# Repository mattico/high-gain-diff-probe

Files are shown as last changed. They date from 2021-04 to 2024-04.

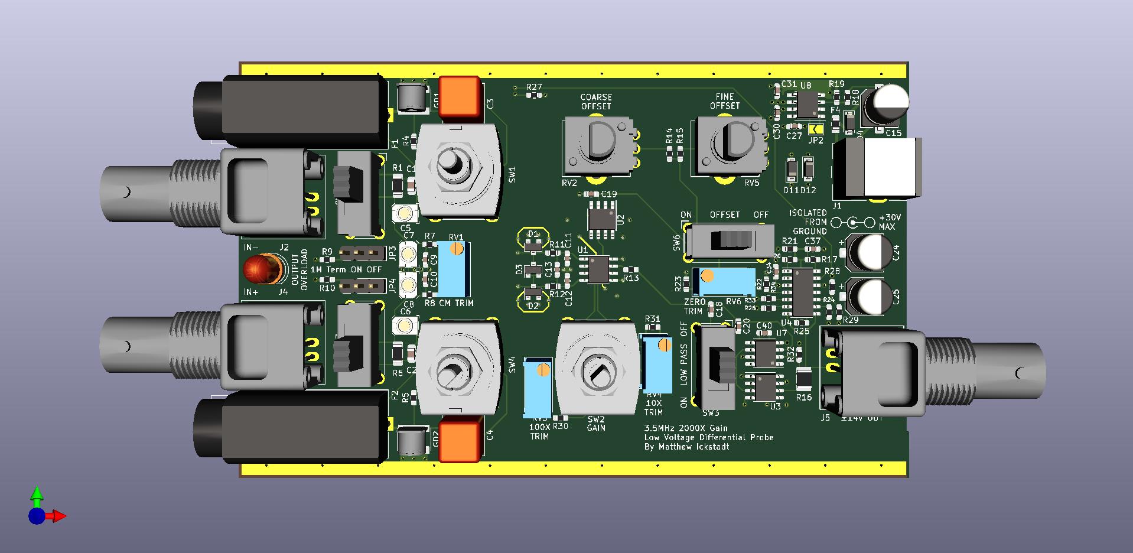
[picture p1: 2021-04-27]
Images/TopRender.jpg

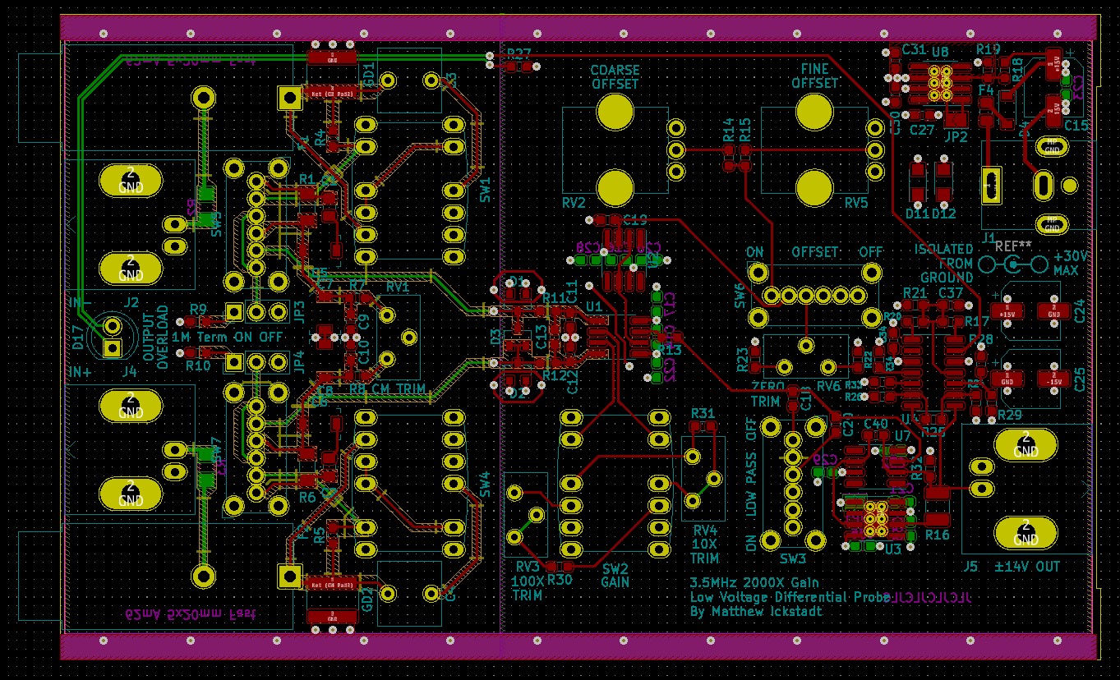
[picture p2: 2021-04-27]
Images/PCBTraces.jpg

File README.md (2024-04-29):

# High Gain Differential Probe

This was my attempt at a high gain (2000X) low-noise differential probe, for use in electronics testing.

Be warned that I haven't gotten this working. IIRC the issue was that it would oscillate or saturate. I didn't look into it too thoroughly, it's possible that there is an easy fix.

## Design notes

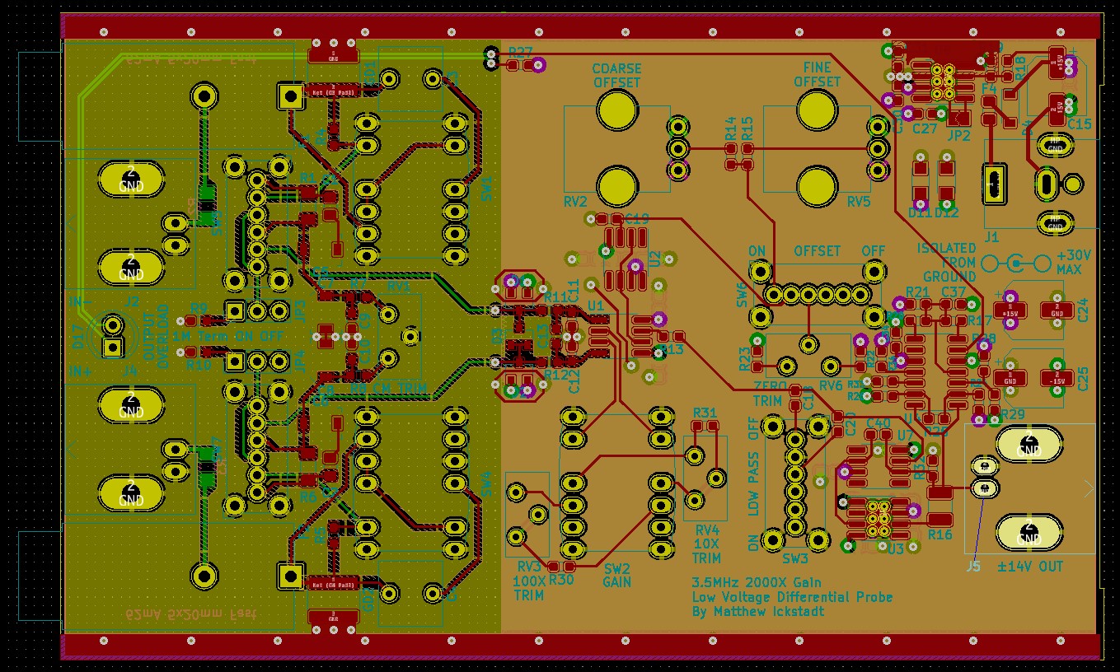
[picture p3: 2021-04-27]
Images/PCBFilled.jpg

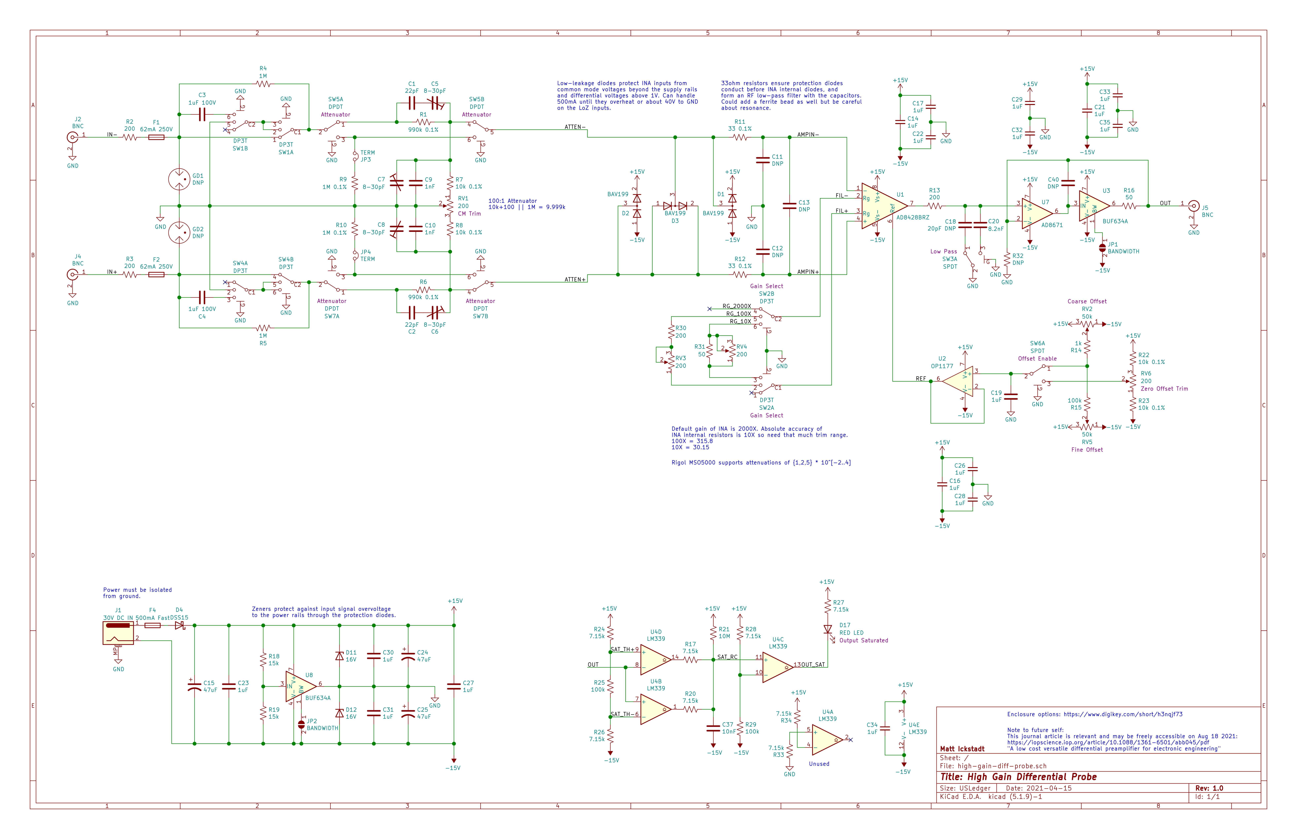
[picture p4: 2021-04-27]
Images/high-gain-diff-probe.png

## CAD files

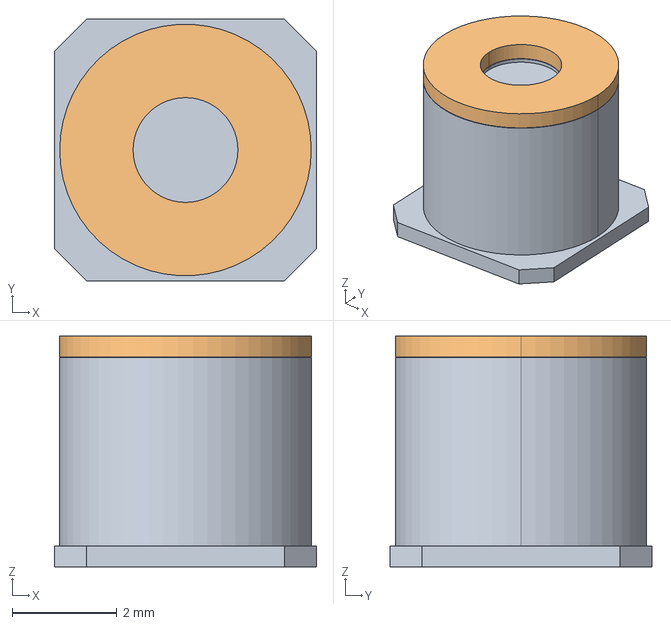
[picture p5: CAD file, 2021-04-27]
3DModel/2031-xxT-sm.stp
5.00 x 5.00 x 4.40 mm

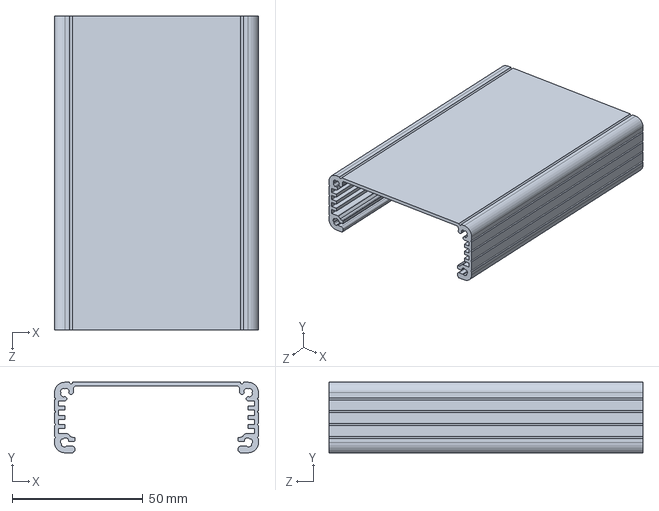
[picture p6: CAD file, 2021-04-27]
3DModel/MechanicalAssembly/Body Extrusion.SLDPRT
78.0 x 27.0 x 120.0 mm

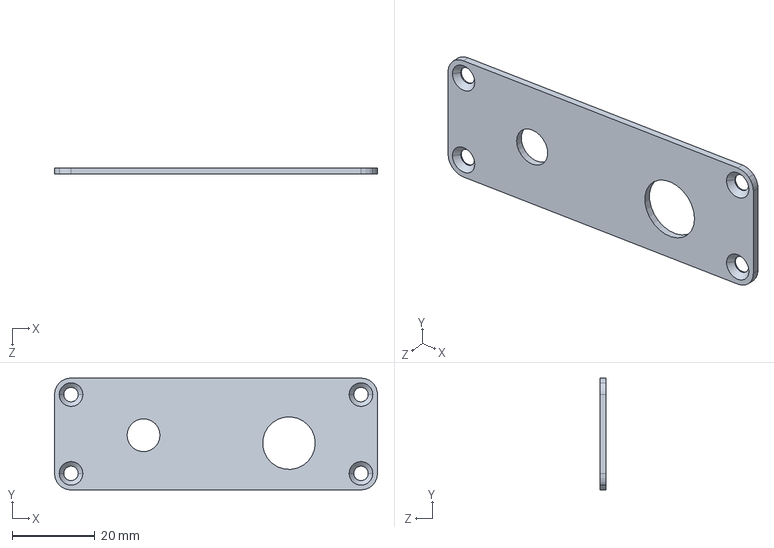
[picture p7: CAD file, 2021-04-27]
3DModel/MechanicalAssembly/Output End Panel.sldprt
78.0 x 27.0 x 1.52 mm

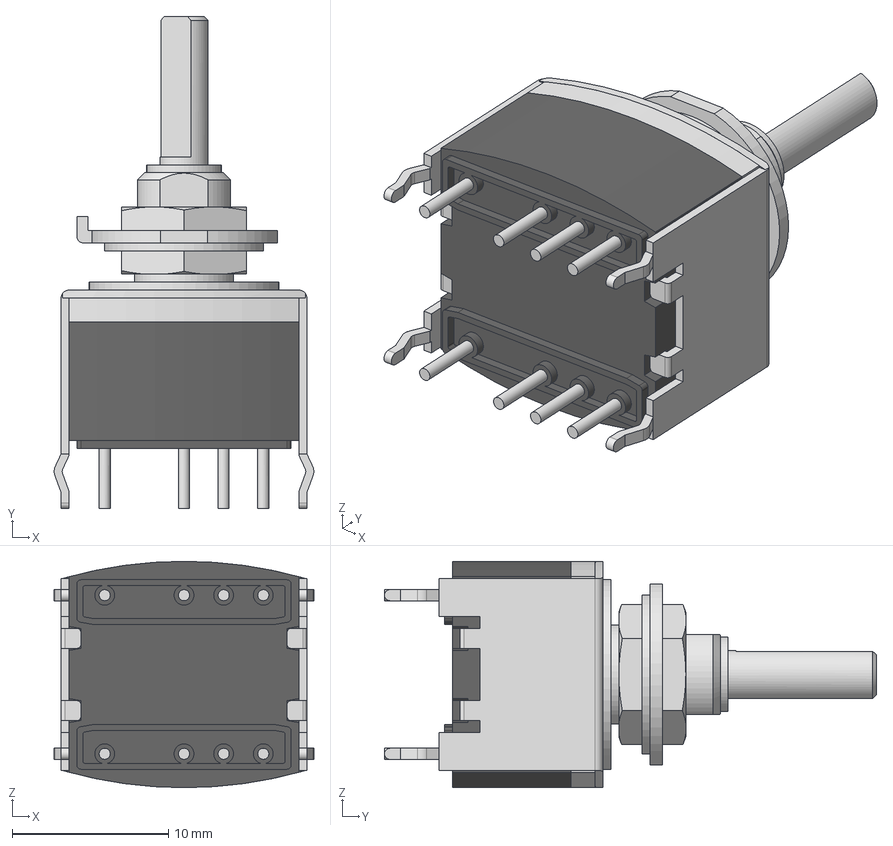
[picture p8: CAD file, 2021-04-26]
3DModel/MRB24B.stp
16.6 x 31.5 x 14.5 mm
_MRB-B-H
_MRB-B-TOP_H
_MRB-MRB-B
_MRB-SHAFT
_AT513M-MRB x 2
_AT509-MRB
_AT545
_MRB24B-terminals

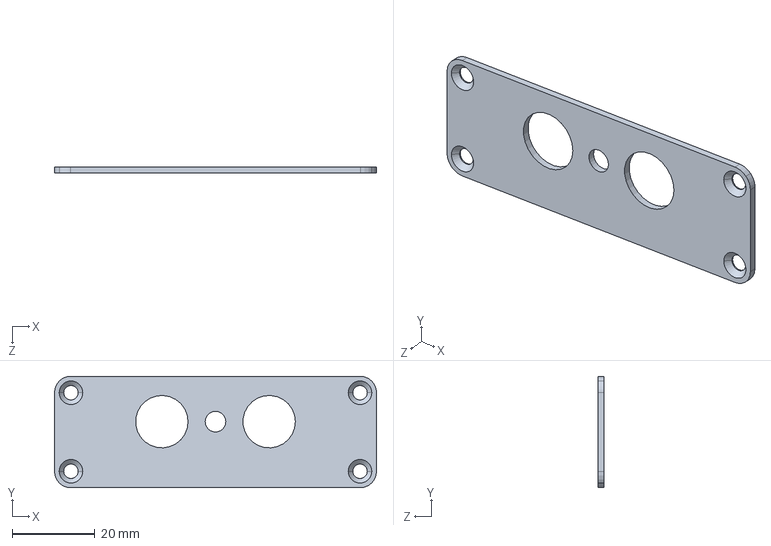
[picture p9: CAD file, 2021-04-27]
3DModel/MechanicalAssembly/Input End Panel.sldprt
78.0 x 27.0 x 1.52 mm

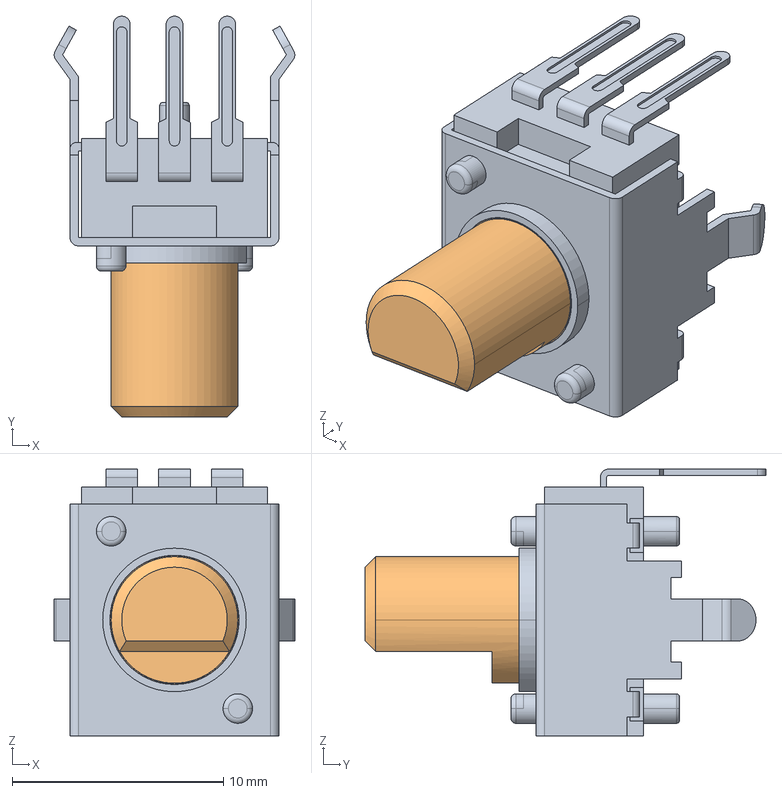
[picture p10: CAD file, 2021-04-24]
3DModel/ptv09a-4x15f-xxxx.stp
11.4 x 19.0 x 12.7 mm

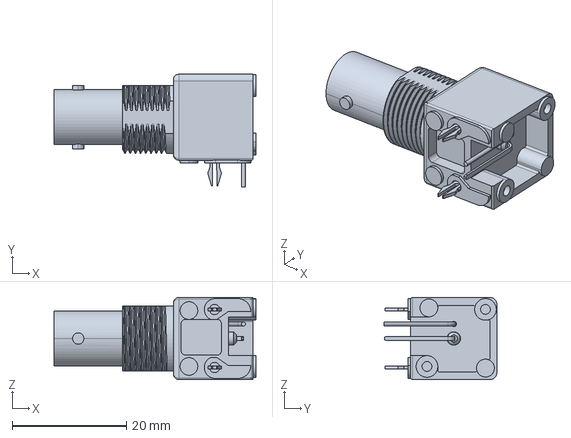
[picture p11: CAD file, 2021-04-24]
3DModel/31-5640-1010.stp
35.4 x 19.8 x 14.4 mm

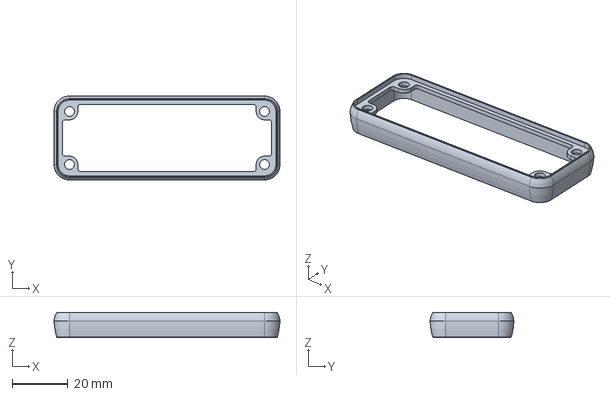
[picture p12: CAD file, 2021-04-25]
3DModel/MechanicalAssembly/J Bezel Open.stp
81.1 x 30.1 x 9.00 mm

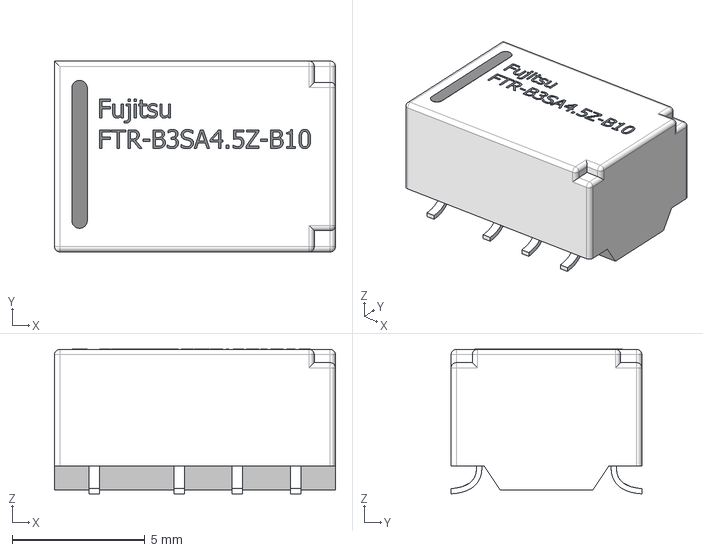
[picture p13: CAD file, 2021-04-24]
3DModel/Fujitsu_-_FTR-B3SA4.5Z-B10.step
10.6 x 7.20 x 5.46 mm

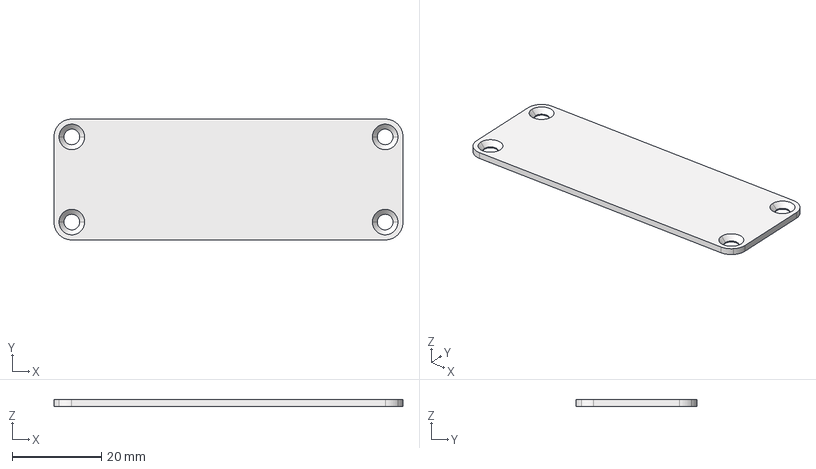
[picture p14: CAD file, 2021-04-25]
3DModel/MechanicalAssembly/J End Panel.stp
78.0 x 27.0 x 1.52 mm

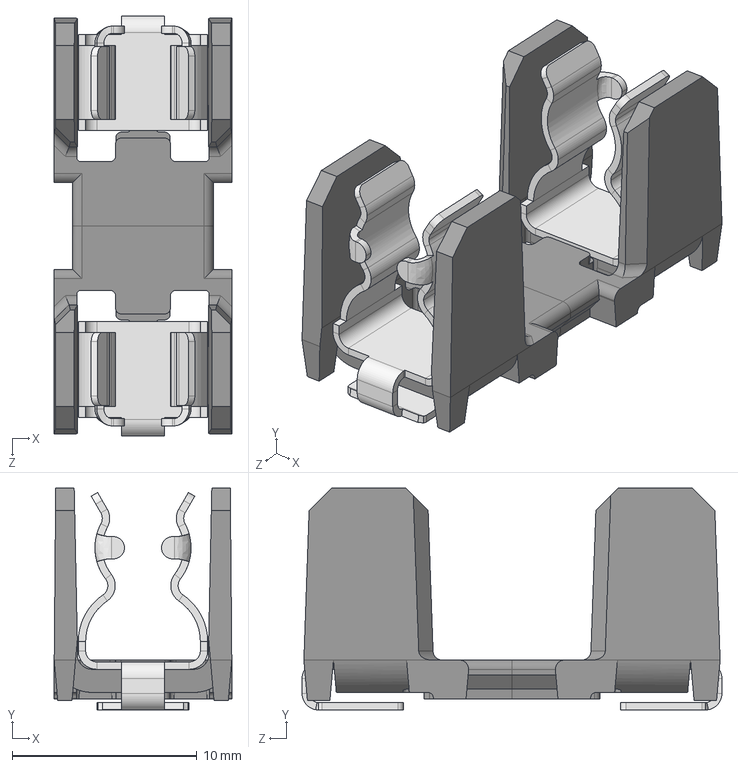
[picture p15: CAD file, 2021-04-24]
3DModel/OGN-SMD_STEP.STEP
9.60 x 12.0 x 22.7 mm

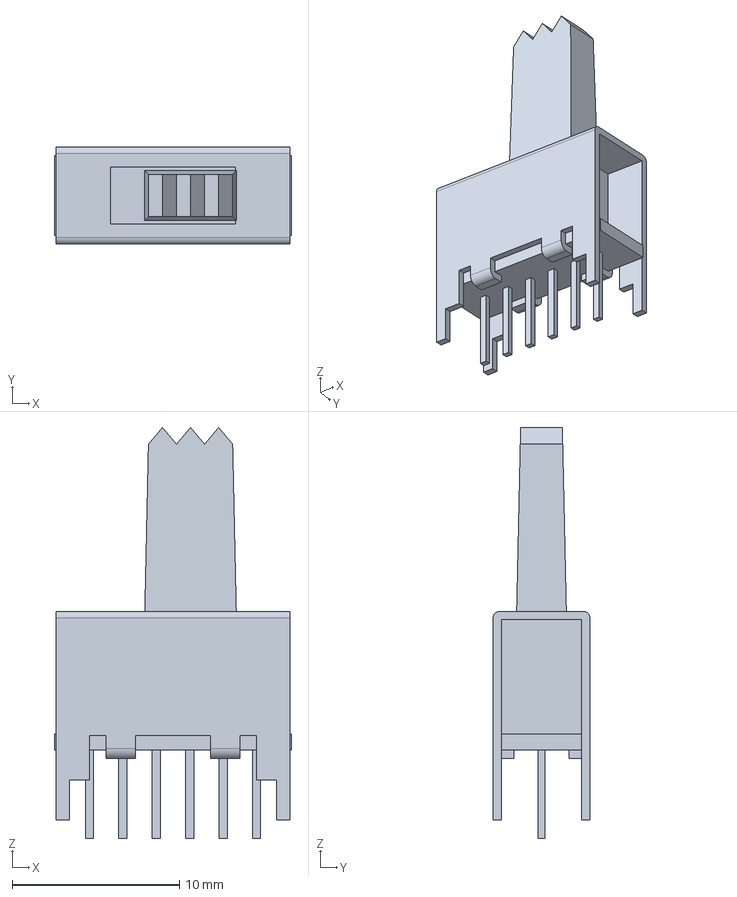
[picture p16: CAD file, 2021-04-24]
3DModel/c-1825263-2-a-3d.igs
14.2 x 5.80 x 24.6 mm

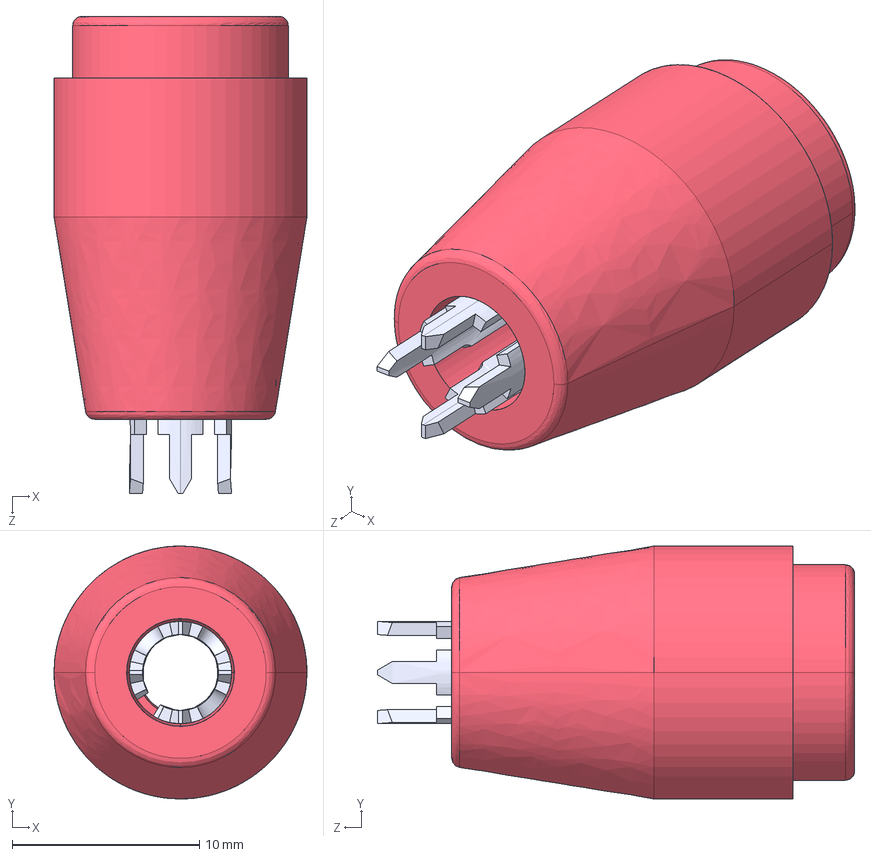
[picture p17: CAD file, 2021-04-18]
3DModel/CT3151V1-2.IGS
13.5 x 13.5 x 25.5 mm

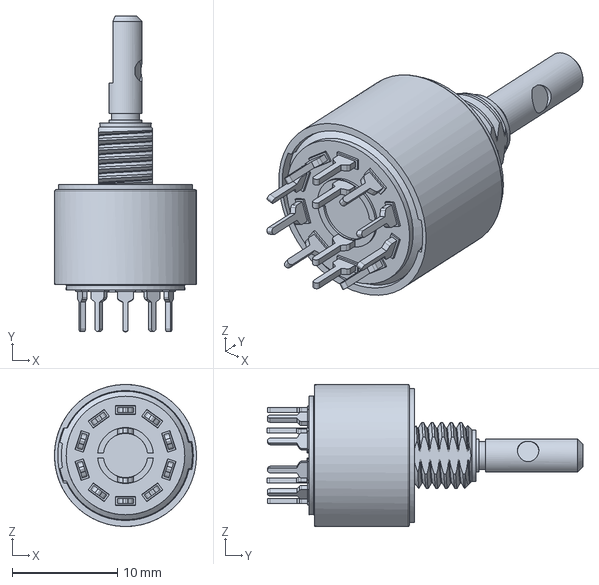
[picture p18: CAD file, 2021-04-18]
3DModel/MB04L1NCGD.stp
13.5 x 30.0 x 13.5 mm

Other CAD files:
3DModel/CT3151V1-0.IGS

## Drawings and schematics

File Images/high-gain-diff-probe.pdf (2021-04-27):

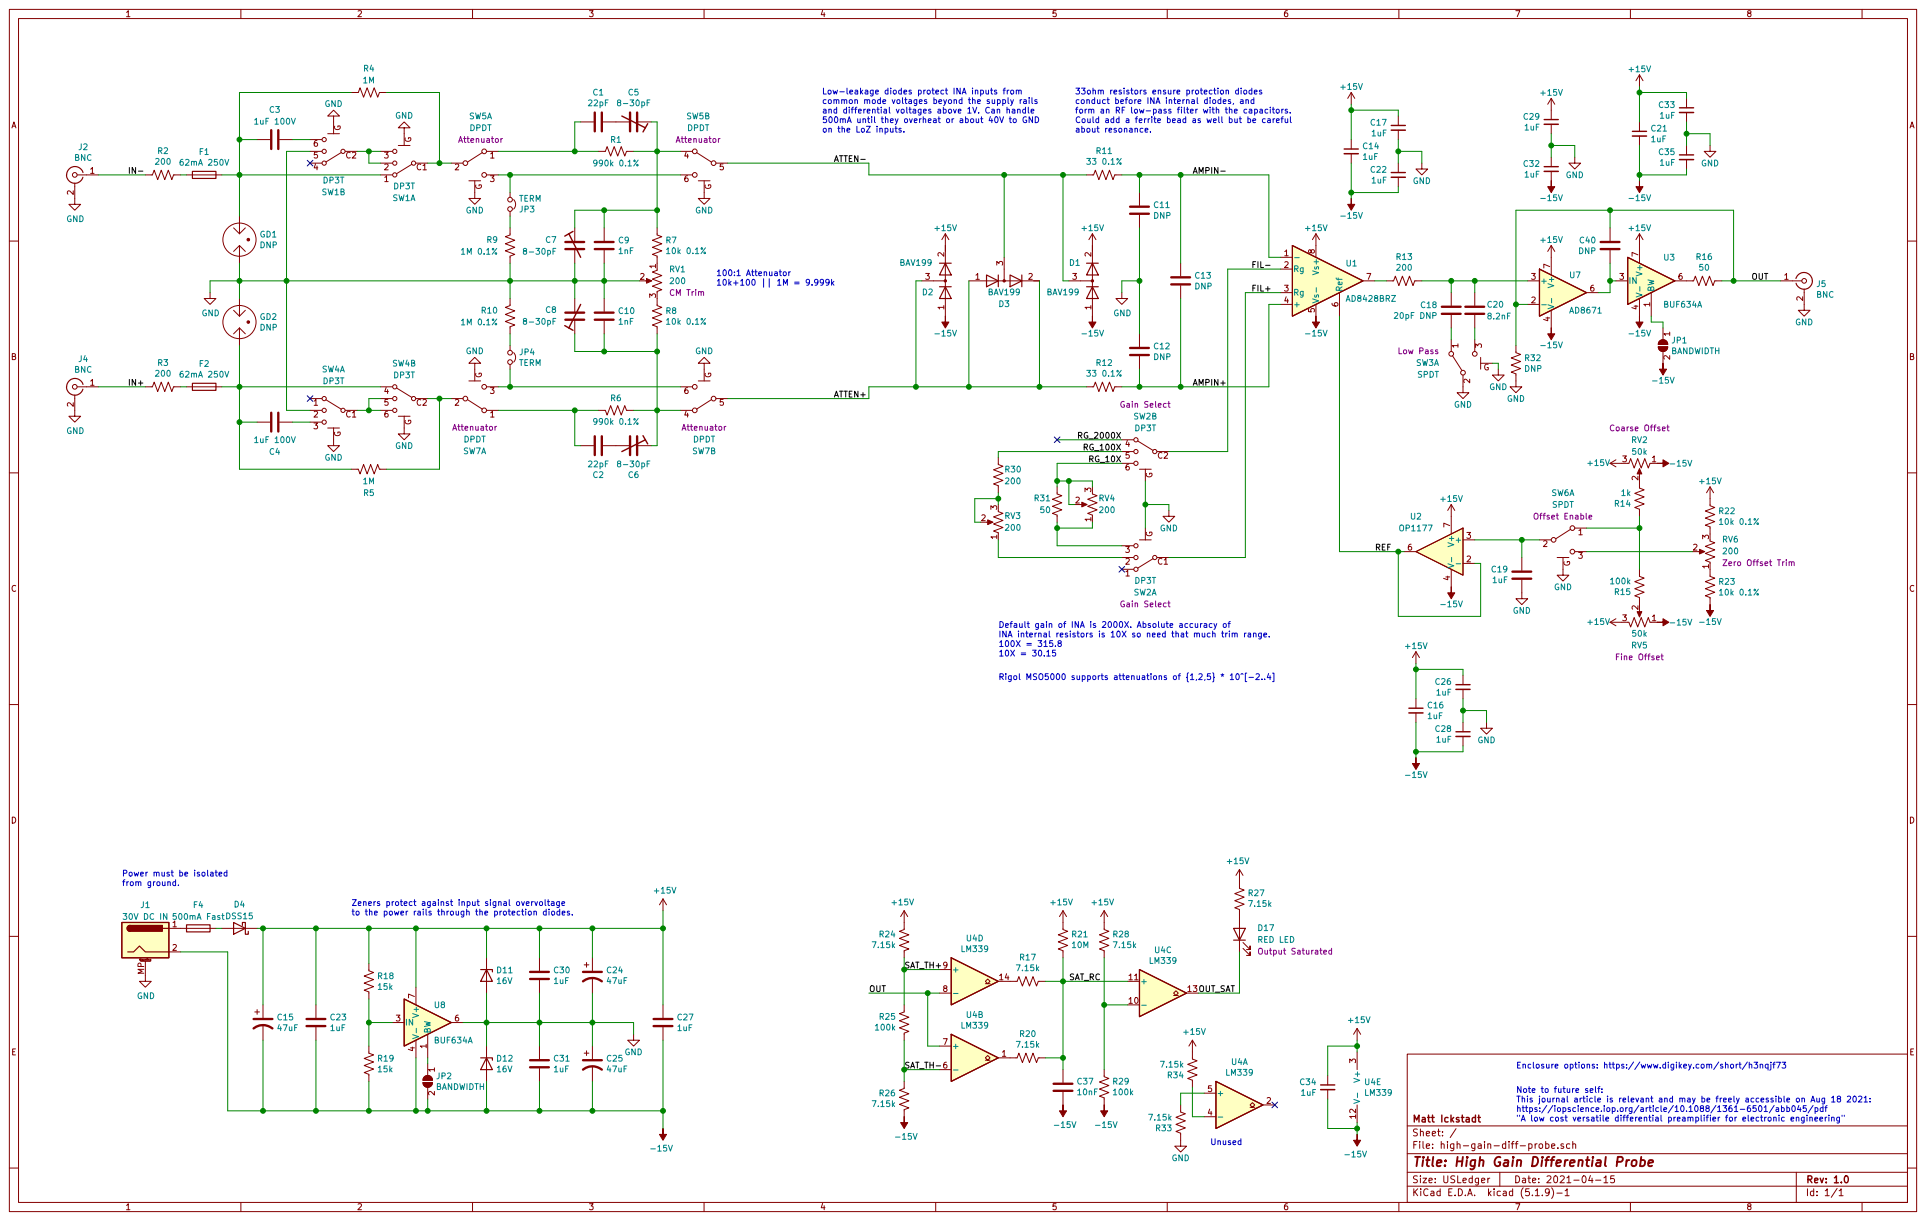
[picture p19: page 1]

form an RF low-pass filter with the capacitors. Could add a ferrite bead as well but be careful about resonance. Low-leakage diodes protect INA inputs from
common mode voltages beyond the supply rails
and differential voltages above 1V. Can handle
500mA until they overheat or about 40V to GND
on the LoZ inputs.

33ohm resistors ensure protection diodes
conduct before INA internal diodes, and

AMPIN-
3D1 BAV199 R30
FIL- FIL+ AMPIN+ Default gain of INA is 2000X. Absolute accuracy of

INA internal resistors is 10X so need that much trim range. 100X = 315.8

Power must be isolated
from ground.

Zeners protect against input signal overvoltage

File: high-gain-diff-probe.sch Sheet: / Matt Ickstadt R18

Enclosure options: https://www.digikey.com/short/h3nqjf73

https://iopscience.iop.org/article/10.1088/1361-6501/abb045/pdf
"A low cost versatile differential preamplifier for electronic engineering"

Id: 1/1 Title: High Gain Differential Probe

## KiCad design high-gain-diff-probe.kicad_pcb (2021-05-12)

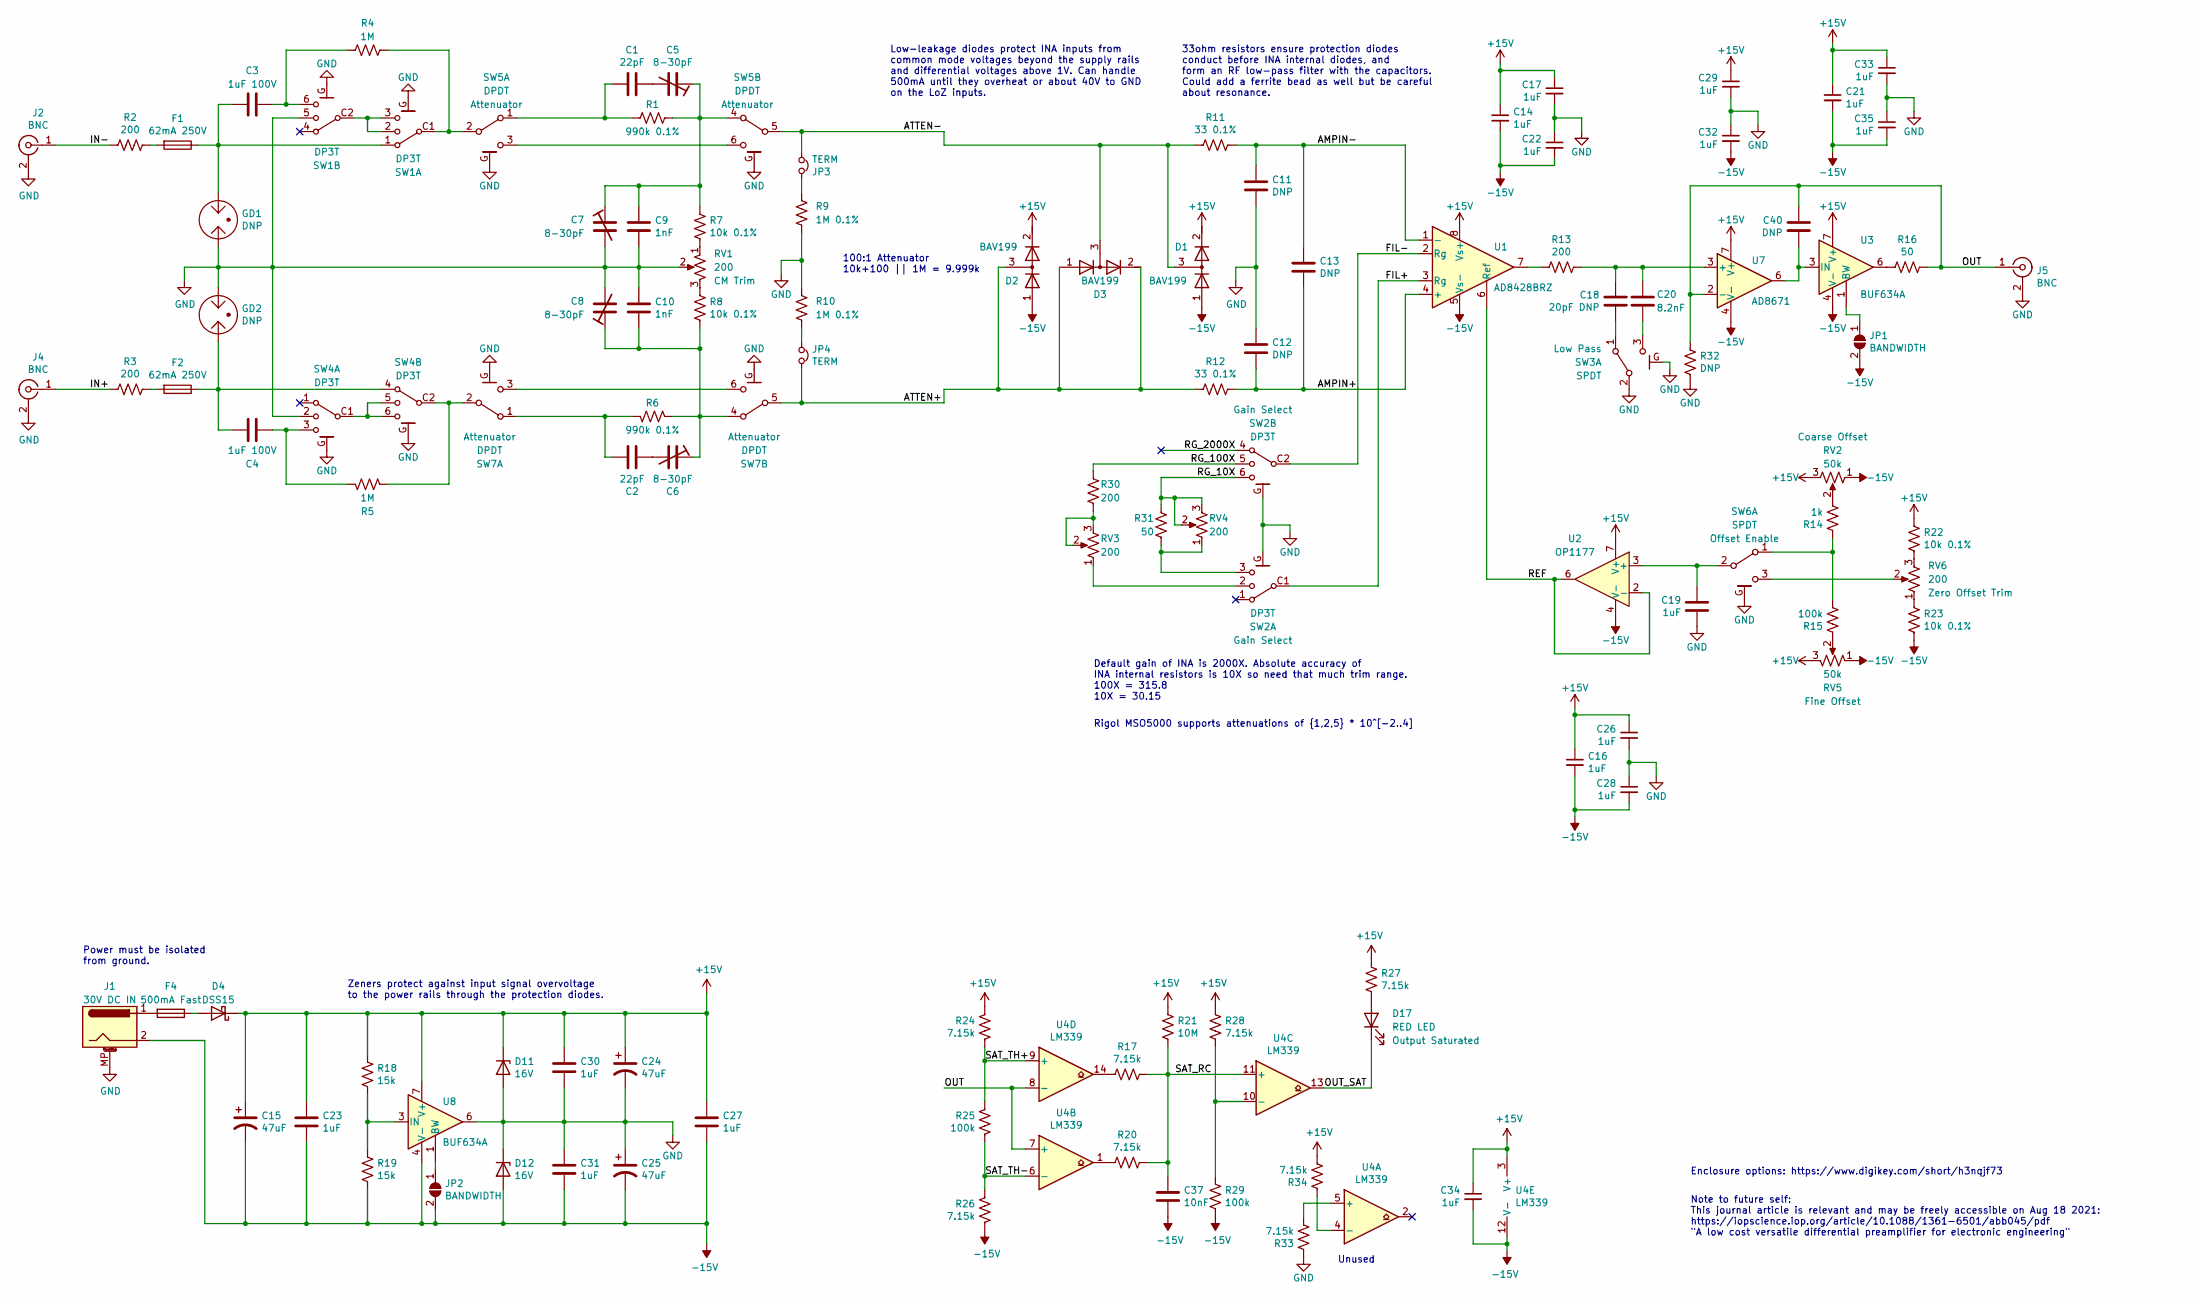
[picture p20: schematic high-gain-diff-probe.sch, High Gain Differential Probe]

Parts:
C1, C2: 22pF; C_0805_2012Metric_Pad1.15x1.40mm_HandSolder; MPN C0805C220J1GACTU
C3, C4: 1uF 100V; C_Rect_L7.2mm_W7.2mm_P5.00mm_FKS2_FKP2_MKS2_MKP2; MPN R82EC4100SH70J
C5, C6, C7, C8: 8-30pF; C_Trimmer_Voltronics_JZ; MPN SGC3S300
C9, C10: 1nF; C_0603_1608Metric_Pad1.05x0.95mm_HandSolder; MPN 0603N102F500CT
C11, C12, C13, C40: DNP; C_0603_1608Metric_Pad1.05x0.95mm_HandSolder
C14, C16, C17, C19, C21, C22, C23, C26, C27, C28, C29, C30, C31, C32, C33, C34, C35: 1uF; C_0603_1608Metric_Pad1.05x0.95mm_HandSolder; MPN CL10A105KL8NNNC
C15, C24, C25: 47uF; CP_Elec_6.3x7.7; MPN A768EB476M1VLAE042
C18: 20pF DNP; C_0603_1608Metric_Pad1.05x0.95mm_HandSolder
C20: 8.2nF; C_0603_1608Metric_Pad1.05x0.95mm_HandSolder; MPN GRM1885C1H822JA01D
C37: 10nF; C_0603_1608Metric_Pad1.05x0.95mm_HandSolder; MPN GRM188R72A103KA01J
D1, D2, D3: BAV199; SOT-23; MPN BAV199,215
D4: DSS15; D_SOD-123; MPN DSS15UTR
D11, D12: 16V; D_SMF; MPN BZD27C16
D17: RED LED; LED_D5.0mm; MPN 151051RS11000
F1, F2: 62mA 250V; Fuseholder_Cylinder-5x20mm_Schurter_FAB_0031-355x_Horizonta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; MPN 0031.3577
F4: 500mA Fast; Fuse_0805_2012Metric_Pad1.15x1.40mm_HandSolder; MPN F0805B0R50FWTR
GD1, GD2: DNP; GDT_Bourns_2031; MPN 2031-15T
J1: 30V DC IN; BarrelJack_CUI_PJ-063AH_Horizontal; MPN PJ-063AH
J2, J4, J5: BNC; BNC_Amphenol_B6252HB-NPP3G-50_Horizontal; MPN 0731385033
JP1, JP2: BANDWIDTH; SolderJumper-2_P1.3mm_Open_TrianglePad1.0x1.5mm
JP3, JP4: TERM; PinHeader_1x03_P2.54mm_Vertical; MPN PR20203VBNN
R1, R6: 990k 0.1%; R_1206_3216Metric_Pad1.30x1.75mm_HandSolder; MPN PTN1206E9903BST1
R2, R3: 200; R_MiniMELF_MMA-0204; MPN SMA-A0204BTNX180R
R4, R5: 1M; R_0603_1608Metric_Pad0.98x0.95mm_HandSolder; MPN RT0603BRD071ML
R7, R8, R22, R23: 10k 0.1%; R_0603_1608Metric_Pad0.98x0.95mm_HandSolder; MPN RT0603BRD1010KL
R9, R10: 1M 0.1%; R_0603_1608Metric_Pad0.98x0.95mm_HandSolder; MPN RT0603BRD071ML
R11, R12: 33 0.1%; R_0603_1608Metric_Pad0.98x0.95mm_HandSolder; MPN RT0603BRD0733RL
R13, R30: 200; R_0603_1608Metric_Pad0.98x0.95mm_HandSolder; MPN RMCF0603FT200R
R14: 1k; R_0603_1608Metric_Pad0.98x0.95mm_HandSolder; MPN CR0603-FX-1001ELF
R15, R25, R29: 100k; R_0603_1608Metric_Pad0.98x0.95mm_HandSolder; MPN RT0603FRE07100KL
R16: 50; R_1210_3225Metric_Pad1.30x2.65mm_HandSolder; MPN RMCF1210FT49R9
R17, R20, R24, R26, R27, R28, R33, R34: 7.15k; R_0603_1608Metric_Pad0.98x0.95mm_HandSolder; MPN RMCF0603FT7K15
R18, R19: 15k; R_0603_1608Metric_Pad0.98x0.95mm_HandSolder; MPN WR06X1502FTL
R21: 10M; R_0603_1608Metric_Pad0.98x0.95mm_HandSolder; MPN RMCF0603JT10M0
R31: 50; R_0603_1608Metric_Pad0.98x0.95mm_HandSolder; MPN RMCF0603FT49R9
R32: DNP; R_0603_1608Metric_Pad0.98x0.95mm_HandSolder
RV1, RV3, RV4, RV6: 200; Potentiometer_Bourns_3296Y_Vertical; MPN 67YR200LF
RV2, RV5: 50k; Potentiometer_Bourns_PTV09A-1_Single_Vertical; MPN PTV09A-4025F-B503
SW1, SW2, SW4: DP3T; SW_NKK_MRB24B; MPN MRB24B
SW3, SW6: SPDT; SW_TE_1825263-2_DPDT; MPN 1825263-2
SW5, SW7: DPDT; SW_TE_1825263-2_DPDT; MPN 1825263-2
U1: AD8428BRZ; SOIC-8_3.9x4.9mm_P1.27mm; MPN AD8428BRZ
U2: OP1177; SOIC-8_3.9x4.9mm_P1.27mm; MPN OP1177ARZ-REEL7
U3, U8: BUF634A; SOIC-8-1EP_3.9x4.9mm_P1.27mm_EP2.41x3.81mm_LargeThermalVias; MPN BUF634AIDDAR
U4: LM339; SOIC-14_3.9x8.7mm_P1.27mm; MPN NJM339CG-TE2
U7: AD8671; SOIC-8_3.9x4.9mm_P1.27mm; MPN AD8671ARZ-REEL7

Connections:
+15V: C14.1, C15.1, C16.1, C17.1, C21.1, C23.1, C24.1, C26.1, C27.1, C29.1, C30.1, C33.1, C34.1, D1.2 (K), D2.2 (K), D4.1 (K), D11.1 (K), R18.1, R21.2, R22.1, R24.2, R27.2, R28.2, R34.1, RV2.3, RV5.3, U1.8 (Vs+), U2.7 (V+), U3.7 (V+), U4.3 (V+), U7.7 (V+), U8.7 (V+)
-15V: C14.2, C15.2, C16.2, C21.2, C22.2, C23.2, C25.2, C27.2, C28.2, C31.2, C32.2, C34.2, C35.2, C37.1, D1.1 (A), D2.1 (A), D12.2 (A), J1.2, JP1.2 (B), JP2.2 (B), R19.2, R23.2, R26.1, R29.1, RV2.1, RV5.1, U1.5 (Vs-), U2.4 (V-), U3.4 (V-), U3.9 (PAD), U4.12 (V-), U7.4 (V-), U8.4 (V-), U8.9 (PAD)
/AMPIN+: C12.2, C13.2, R12.1, U1.4 (+)
/AMPIN-: C11.1, C13.1, R11.1, U1.1 (-)
/ATTEN+: D2.3 (common), D3.1 (A), D3.2 (K), JP4.2, R12.2, SW7.5 (B)
/ATTEN-: D1.3 (common), D3.3 (common), JP3.2, R11.2, SW5.5 (B)
/FIL+: SW2.C1 (C2), U1.3 (Rg)
/FIL-: SW2.C2, U1.2 (Rg)
/IN+: J4.1 (In), R3.2
/IN-: J2.1 (In), R2.2
/OUT: C40.1, J5.1 (In), R16.1, R32.1, U4.7 (+), U4.8 (-), U7.2 (-)
/OUT_SAT: D17.1 (K), U4.13
/REF: U1.6 (Ref), U2.2 (-), U2.6
/RG_10X: R31.2, RV4.2, RV4.3, SW2.6
/RG_100X: R30.1, SW2.5
/SAT_RC: C37.2, R17.1, R20.1, R21.1, U4.11 (+)
/SAT_TH+: R24.1, R25.2, U4.9 (+)
/SAT_TH-: R25.1, R26.2, U4.6 (-)
GND: C7.2, C8.2, C9.2, C10.1, C11.2, C12.1, C17.2, C19.1, C22.1, C24.2, C25.1, C26.2, C28.1, C29.2, C30.2, C31.1, C32.1, C33.2, C35.1, D11.2 (A), D12.1 (K), GD1.1, GD2.3, J1.MP (MountPin), J2.2 (Ext), J4.2 (Ext), J5.2 (Ext), R9.2, R10.1, R32.2, R33.2, RV1.2, SW1.5, SW1.G, SW2.G, SW3.2 (B), SW3.G, SW4.2 (5), SW4.G, SW5.G, SW6.G, SW7.G, U8.6
unnamed: C1.1, C5.2
unnamed: C1.2, R1.2, SW5.1 (A)
unnamed: C2.1, C6.2
unnamed: C2.2, R6.2, SW7.1 (A)
unnamed: C3.1, R4.1, SW1.6
unnamed: C3.2, F1.1, GD1.3, SW1.1 (4)
unnamed: C4.1, R5.1, SW4.3 (6)
unnamed: C4.2, F2.1, GD2.1, SW4.4
unnamed: C5.1, C7.1, C9.1, R1.1, R7.1, SW5.4 (A)
unnamed: C6.1, C8.1, C10.2, R6.1, R8.2, SW7.4 (A)
unnamed: C18.1, C20.1, R13.1, U7.3 (+)
unnamed: C18.2, SW3.1 (A)
unnamed: C19.2, SW6.2 (B), U2.3 (+)
unnamed: C20.2, SW3.3 (C)
unnamed: C40.2, U3.3 (IN), U7.6
unnamed: D4.2 (A), F4.1
unnamed: D17.2 (A), R27.1
unnamed: F1.2, R2.1
unnamed: F2.2, R3.1
unnamed: F4.2, J1.1
unnamed: JP1.1 (A), U3.1 (BW)
unnamed: JP2.1 (A), U8.1 (BW)
unnamed: JP3.1, R9.1
unnamed: JP4.1, R10.2
unnamed: R4.2, SW1.C1 (C2), SW5.2 (B)
unnamed: R5.2, SW4.C2, SW7.2 (B)
unnamed: R7.2, RV1.1
unnamed: R8.1, RV1.3
unnamed: R13.2, U1.7
unnamed: R14.1, R15.2, SW6.1 (A)
unnamed: R14.2, RV2.2
unnamed: R15.1, RV5.2
unnamed: R16.2, U3.6
unnamed: R17.2, U4.14
unnamed: R18.2, R19.1, U8.3 (IN)
unnamed: R20.2, U4.1
unnamed: R22.2, RV6.3
unnamed: R23.1, RV6.1
unnamed: R28.1, R29.2, U4.10 (-)
unnamed: R30.2, RV3.2, RV3.3
unnamed: R31.1, RV4.1, SW2.3 (6)
unnamed: R33.1, U4.5 (+)
unnamed: R34.2, U4.4 (-)
unnamed: RV3.1, SW2.2 (5)
unnamed: RV6.2, SW6.3 (C)
unnamed: SW1.2 (5), SW1.3 (6), SW1.C2
unnamed: SW4.5, SW4.6, SW4.C1 (C2)
unnamed: SW5.3 (C), SW5.6 (C)
unnamed: SW7.3 (C), SW7.6 (C)

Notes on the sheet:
Low-leakage diodes protect INA inputs from common mode voltages beyond the supply rails and differential voltages above 1V. Can handle 500mA until they overheat or about 40V to GND on the LoZ inputs.
33ohm resistors ensure protection diodes conduct before INA internal diodes, and form an RF low-pass filter with the capacitors. Could add a ferrite bead as well but be careful about resonance.
Default gain of INA is 2000X. Absolute accuracy of INA internal resistors is 10X so need that much trim range. 100X = 315.8 10X = 30.15
Rigol MSO5000 supports attenuations of {1,2,5} * 10^[-2..4]
100:1 Attenuator 10k+100 || 1M = 9.999k
Note to future self: This journal article is relevant and may be freely accessible on Aug 18 2021: https://iopscience.iop.org/article/10.1088/1361-6501/abb045/pdf "A low cost versatile differential preamplifier for electronic engineering"
Enclosure options: https://www.digikey.com/short/h3nqjf73
Power must be isolated from ground.
Zeners protect against input signal overvoltage to the power rails through the protection diodes.
Unused

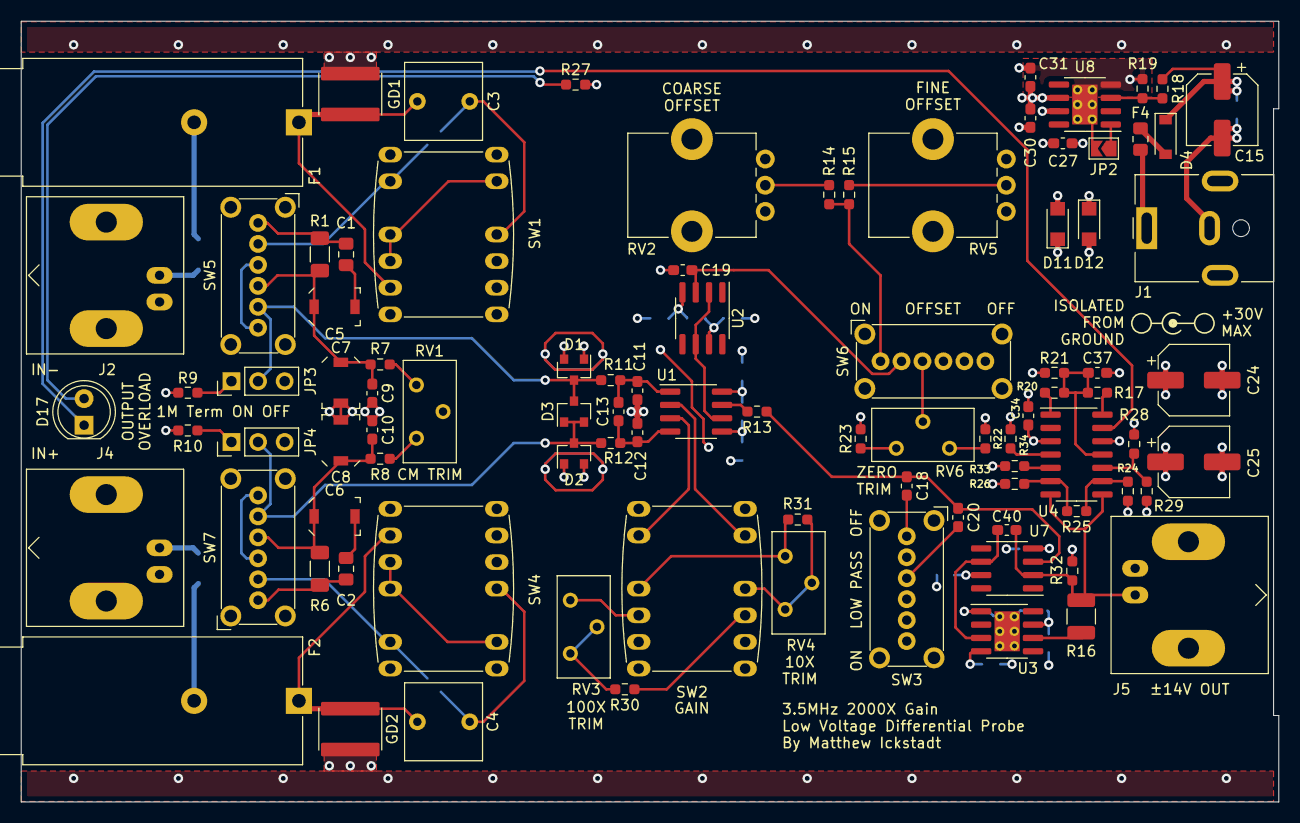
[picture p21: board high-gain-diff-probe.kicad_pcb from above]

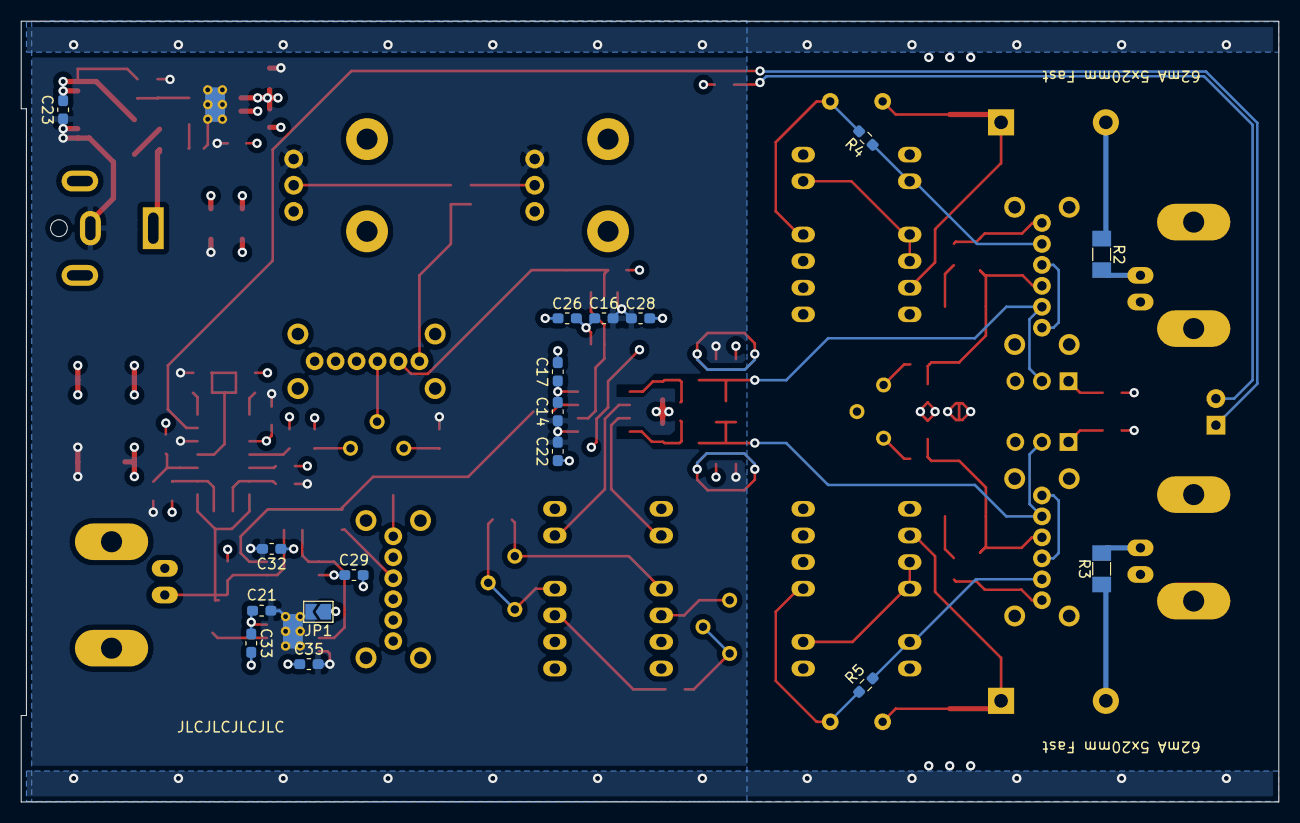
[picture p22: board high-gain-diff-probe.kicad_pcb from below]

Board: 4 copper layers, 120.0 x 74.5 mm, 110 parts (17 on the bottom side), 68 nets.

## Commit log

2021-04-16 Schematic 1st pass
    [high-gain-diff-probe.kicad_pcb, high-gain-diff-probe.sch]
2021-04-16 Transformer driver?
    [high-gain-diff-probe.sch]
2021-04-17 Improve input divider ratio
    [high-gain-diff-probe.sch]
2021-04-17 Improve simulations
    [high-gain-diff-probe.sch]
2021-04-17 Implement capacitance multiplier, power overvoltage protection, and signal out of range comparators
    [high-gain-diff-probe.sch]
2021-04-17 Add notes to schematic
    [high-gain-diff-probe.sch]
2021-04-17 Add footprints to most parts
    [high-gain-diff-probe.sch]
2021-04-17 Add footprints for everything
    [high-gain-diff-probe.kicad_pcb, high-gain-diff-probe.sch]
2021-04-17 Begin layout
    [high-gain-diff-probe.kicad_pcb, high-gain-diff-probe.sch]
2021-04-18 Continue layout
    [CT3151V1-0.IGS, CT3151V1-2.IGS, MB04L1NCGD.stp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]
2021-04-20 'finish' analog section
    [high-gain-diff-probe.sch]
2021-04-21 Implement boost power
    [high-gain-diff-probe.kicad_pcb, high-gain-diff-probe.sch]
2021-04-21 Try out other power supplies
2021-04-22 Simplify power
    [high-gain-diff-probe.kicad_pcb, high-gain-diff-probe.sch]
2021-04-23 More layout
    [high-gain-diff-probe.kicad_pcb, high-gain-diff-probe.sch]
2021-04-24 Add 3D Models
    [31-5640-1010.stp, Fujitsu_-_FTR-B3SA4.5Z-B10.step, OGN-SMD_STEP.STEP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]
2021-04-24 Finish Layout
    [high-gain-diff-probe.kicad_pcb, high-gain-diff-probe.sch]
2021-04-24 Add images, layout tweaks.
    [high-gain-diff-probe.kicad_pcb, high-gain-diff-probe.sch]
2021-04-24 Add info to silkscreen
    [high-gain-diff-probe.kicad_pcb, high-gain-diff-probe.sch]
2021-04-24 Add Gerbers
    [high-gain-diff-probe-B_Cu.gbl, high-gain-diff-probe-B_Mask.gbs, high-gain-diff-probe-B_Paste.gbp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]
2021-04-24 Use larger thermal vias for cheaper PCBs
    [high-gain-diff-probe-B_Cu.gbl, high-gain-diff-probe-B_Mask.gbs, high-gain-diff-probe-B_Paste.gbp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]
2021-04-24 Connect thermal vias to plane solidly
    [high-gain-diff-probe-B_Cu.gbl, high-gain-diff-probe-B_Mask.gbs, high-gain-diff-probe-B_Paste.gbp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]
2021-04-24 Add MPNs for everything else
    [high-gain-diff-probe-B_Cu.gbl, high-gain-diff-probe-B_Mask.gbs, high-gain-diff-probe-B_Paste.gbp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]
2021-04-25 Add mechanical models. Tweak LED Position.
    [Input End Panel.sldprt, J Bezel Open.stp, J End Panel.stp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]
2021-04-25 Tweak layout
    [high-gain-diff-probe-B_CrtYd.gbr, high-gain-diff-probe-B_Cu.gbl, high-gain-diff-probe-B_Fab.gbr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]
2021-04-25 Fix 10K MPN
    [high-gain-diff-probe.kicad_pcb, high-gain-diff-probe.sch]
2021-04-25 Update images, gerbers
    [high-gain-diff-probe-B_CrtYd.gbr, high-gain-diff-probe-B_Cu.gbl, high-gain-diff-probe-B_Fab.gbr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]
2021-04-26 Begin work on new version with no relays and manual attenuator switching
    [MRB24B.stp, high-gain-diff-probe.kicad_pcb, high-gain-diff-probe.sch]
2021-04-27 Complete major layout of no-relay design
    [high-gain-diff-probe.kicad_pcb, high-gain-diff-probe.sch]
2021-04-27 Layout Tweaks
    [high-gain-diff-probe.kicad_pcb, high-gain-diff-probe.sch]
2021-04-27 Update gerbers and 3d models
    [Body Extrusion.SLDPRT, Input End Panel.sldprt, J Bezel Open.stp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]
2021-04-27 Overengineer Comparator
    [2031-xxT-sm.stp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]
2021-04-28 Fix AC coupling resistor
    [high-gain-diff-probe.kicad_pcb, high-gain-diff-probe.sch]
2021-05-01 Update gerbers
    [high-gain-diff-probe-B_CrtYd.gbr, high-gain-diff-probe-B_Cu.gbl, high-gain-diff-probe-B_Fab.gbr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]
2021-05-12 Fix termination
    [high-gain-diff-probe.kicad_pcb, high-gain-diff-probe.sch]

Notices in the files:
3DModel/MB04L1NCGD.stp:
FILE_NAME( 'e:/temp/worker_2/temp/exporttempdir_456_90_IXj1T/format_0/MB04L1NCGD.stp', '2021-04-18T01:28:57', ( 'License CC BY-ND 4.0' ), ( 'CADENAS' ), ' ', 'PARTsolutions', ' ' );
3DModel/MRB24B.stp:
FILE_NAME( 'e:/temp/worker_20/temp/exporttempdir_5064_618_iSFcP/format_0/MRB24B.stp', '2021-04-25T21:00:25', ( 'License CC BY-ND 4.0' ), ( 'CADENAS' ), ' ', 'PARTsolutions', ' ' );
